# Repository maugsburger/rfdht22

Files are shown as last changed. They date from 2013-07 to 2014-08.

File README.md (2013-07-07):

rfdht22
=======

RF temp/hum sensor, grown from a DHT22 and NRF24L01p based sensor to something bigger.

Originally, I just wanted to monitor humidity and temperature in all rooms of my flat, submit them wireless to a master where you can read them out and get some other fancy features (eg close all windows, now it's warmer on the outside than inside).

sensor
------

With every step of hardware design, it grew a little bit bigger, so there are two different version right now:

- either a small headless version with dht22 or one-wire and i2c, powered by attiny2313a, as cheap as possible (single sided with some bridges)

- or a big version with lcd, twi/i2c, one-wire, quad direct analogue and quad opamp driven analogue in

One design goal was to make the sensors as power saving as possible, so they will hopefully run multiple years on a pair of AA cells. No wires, no problem with WAF.

master
------

Power doesn't matter here, big ass display (currently only 4x20 character LCD), can show values of all sensors, and a lot of planned features still in my head.

possible improvements
---------------------

 - lan interface for master
 - hack some radiator controller to enable remote control

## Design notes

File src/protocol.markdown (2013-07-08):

# RF Communication Protocol/Procedure

## Terms

* Sensor: autonomous device with probes attached to it, every sensor has its
  own 7-bit-id in range `0x01` to `0xFF`).
    * Probe: Every single measurement device attached to a sensor
* Master: device recieving all measurements for further processing, ID is
  always `0x00`
* PTX: The sender, initiating communication, here every sensors
* PRX: The reciever, can't initiate transfer on it's own, here the master

## Adresses and Data Pipes

The used [nRF24L01+][0] chip has the ability to divide the data stream into up
to six data pipes, identified by unique addresses.

Each address consists of up to 5 bytes, with the following requirements:

<table>
<tr><th></th><th>Byte4</th><th>Byte3</th><th>Byte2</th><th>Byte1</th><th>Byte0</th></tr>
<tr><th>Pipe0</th><td>0b4</td><td>0b3</td><td>0b2</td><td>0b1</td><td>addr0</td></tr>
<tr><th>Pipe1</th><td>b4</td><td>b3</td><td>b2</td><td>b1</td><td>addr1</td></tr>
<tr><th>Pipe2</th><td>b4</td><td>b3</td><td>b2</td><td>b1</td><td>addr2</td></tr>
<tr><th>Pipe3</th><td>b4</td><td>b3</td><td>b2</td><td>b1</td><td>addr3</td></tr>
<tr><th>Pipe4</th><td>b4</td><td>b3</td><td>b2</td><td>b1</td><td>addr4</td></tr>
<tr><th>Pipe5</th><td>b4</td><td>b3</td><td>b2</td><td>b1</td><td>addr5</td></tr>
</table>

As a special requirement, addr0-addr5 must be different.

Pipe0 will be used as a general transmit permission request line with
`addr0=0x00`, and every further pipe gets dynamically assigned to a sensors,
using the sensors ID as addrX.

Only 3 byte adresses will be used, so the sent packages can be shorter.
Therefore, byte2 and byte1 are the unique system id, byte3 and byte4 are unused

## Auto-Ack and Payload

In my reading of the datasheet, Auto-Ack always takes the payload in the TX
FIFO of PRX and sends it to the PTX. As there can be only 3 payloads pending,
there is no benifit in using more than 3 data pipes and therefore 2 sensor
connections at once.

Pipe0 has Auto-Ack disabled, so that the master has time to put the specific
reply packet in the TX buffer. 

A communication process will look like the following:

1. PTX sends out communication request packet on Pipe0
    * free pipe: 
        1. set up pipeX with sensors id as addrX
        1. put ack packet into tx fifo for pipeX
        1. send out ack with sensor id as payload
    * no free pipe:
        1. ack with payload 0x00
1. PTX sends out transfer config/informational packet on pipeX
    * master auto acks with informational data packet
1. PTX sends out one packet for every reading
    * master auto acks

## RF Packets, rev0

### Pipe0 request

    payload[0] = sensor_id
    payload[1], lower nibble = packet design revision = 0x0
    payload[1], higher nibble = desired action
        bit4    data
        bit5    config
        bit6    unused
        bit7    new_sensor (sensor_id must be 0 here!)
        exactly one bit must be set

### Pipe0 ACK

    payload[0] = sensor_id (set to assigned sensor_id in case of config)
    payload[1], lower nibble = packet design revision (if smaller than
        requested, this is max. revision of master and comm is terminated)
    payload[1], higher nibble = repeat and confirm desired action
        bit4    ack data
        bit5    ack config
        bit6    unused
        bit7    ack new_sensor (set sensor_id!)
        no bit set means no free transmit pipe, try again later

### Data
#### PipeX first packet

    payload[0] = battery reading
        0x00        => empty with comparator
        0xFF        => not empty with comparator
        0x01-0xFE   => voltage in .02 volt steps (up to 5.1V)
    payload[1], lower nibble = number of readings to transmit (up to 16)
    payload[1], higher nibble = needs update

#### PipeX first ACK

    payload[0] = transmit interval in 30s steps
    payload[1], lower nibble = outdoor brightness (adjust leds brightness)
    payload[1], higher nibble = unused

#### PipeX reading packets

    payload[0], xxDDPPPP
        xx      unused
        PPPP    probe id
        DD      bytes data to be recieved
    payload[1…4] = one to four probe data bytes

#### PipeX reading ACK

Auto-generated, empty
    
### Config

Althoug it would be nice to make the sensors configurable via master, this
feature is currently not available, because it would make the master need to
know about all sensors config details. This may be implemented in a future
protocol version.

There is no message back to the sensor if all masters probe channels are used,
too. In this case the sensors state is "all configured", but the master doesn't
know about the probes. 

#### PipeX config packet

As there can be up 32 bytes in a packet, but a sensor can only hold up to 16
probes, we just send a list of all sensors unit bytes.

    payload[n] = unit-data of sensor n

#### PipeX ACK

Auto-generated, empty

### New Sensor

No packets are needed, communication is over after Pipe0 ACK, but the
client should start a config dialogue directly afterwards.

## Thoughts
Up to 16 probes per sensor should be enough, else we need a sensor talking to
master as more than 1 sensor. 

Initially we need to brief the master about the known probes, especially their
data format and unit used. This should be splitted into two seperate processes,
a pairing of the sensor with the master (once) and probe configuration (every
time the probes change/new ones are added).

[0]: http://www.nordicsemi.com/kor/nordic/download_resource/8765/2/8827113 "nRF24L01+"

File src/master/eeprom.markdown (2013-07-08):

# EEPROM

Master has at least 2kB of EEPROM, splittet in blocks of 256 bytes here.

With this layout, there are 511 bytes for general usage available, the sensor
and probe data takes 1537 bytes.

Up to 255 sensors can be connected, combined with up to 1024 probes. Every char
in sensor description decrements the available sensor count by one.

## First kB
    0x000…0x01f automatically assigned
        free_sensor_id  first currently unused sensor id
    0x200…0x2ff sensor and probe data start – high section
        0x200: first free probe unit data byte (0x4LL…0x7LL) and length of
                sensor0 description text
        0x201…0x2ff: sensor1-255 probe data start byte (0x4LL…0x7LL) and length of
                sensor1-255 description text
        TTTTTTHH
        TTTTTT  0-64 chars of descriptive text
        HH      0-3 high sector, 0x4LL - 0x7LL
    0x300…0x3ff sensor and probe data start – low section
        0x300: first free probe unit data byte (0xH00…0xHff)
        0x301…0x3ff: sensor1-255 probe data start byte (0xH00…0xHff)

## Second kB
    1024 bytes of "shared" unit data/description string memory
    0x400…0x4ff probe0-255 unit data, according to units.md
    0x500…0x5ff 
    0x600…0x6ff
    0x700…0x7ff

# Examples
## Sensor/Probe Data

Setup with two sensors, first named 'TEST' has 2 probes temp and hum, second
named 'Foo23' has only one temp sensor
   
    free_sensor_id = 2

    0x200   00010000
            TTTTTTHH
            => TTTTTT = 100 => 4 bytes/chars of descriptive text for sensor0
            => HH = 00      => first free high byte is 0x4LL
    0x300   00001100        => first free low byte is  0xH0c

    0x201   00010100
            TTTTTTHH
            => TTTTTT = 101 => 5 bytes/chars of descriptive text for sensor1
            => HH = 00      => data start high byte is 0x4LL
    0x301   00000110        => data start low byte is  0xH06

    0x202…0x2ff --unused--
    0x302…0x3ff --unused--

    0x400   0x54    => 'T'
    0x401   0x60    => 'E'
    0x402   0x53    => 'S'
    0x403   0x54    => 'T'
    0x404   0x40    => °C, divide by 10
    0x405   0x41    => % hum, divide by 10
    0x406   0x46    => 'F'
    0x407   0x6F    => 'o'
    0x408   0x6F    => 'o'
    0x409   0x32    => '2'
    0x40a   0x33    => '3'
    0x40b   0x40    => °C, divide by 10
    0x40c…0x7ff --unused--

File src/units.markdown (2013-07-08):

# Available units

    one byte data, PPUU UUUU

6 bits available for unit

    0x00    °C
    0x01    % hum
    …
    0x3F

2 bits available for prescaling

   00   do nothing
   01   divide by 10
   10   divide by 100
   11   divide by 1000

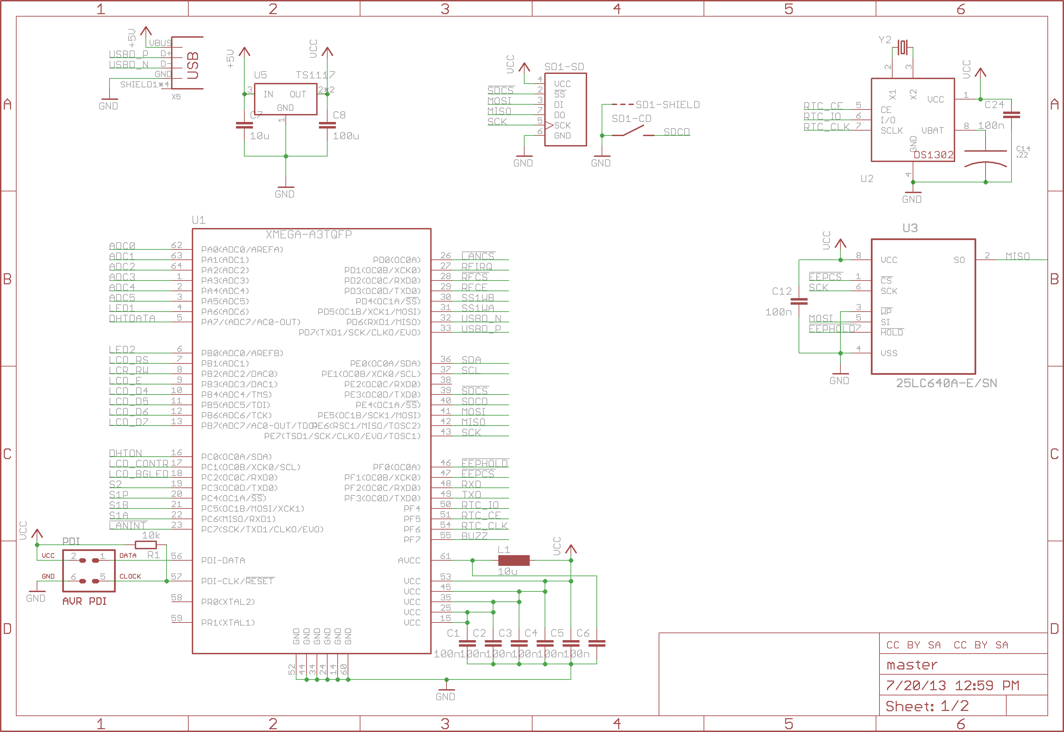
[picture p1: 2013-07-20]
master_sheet1.png

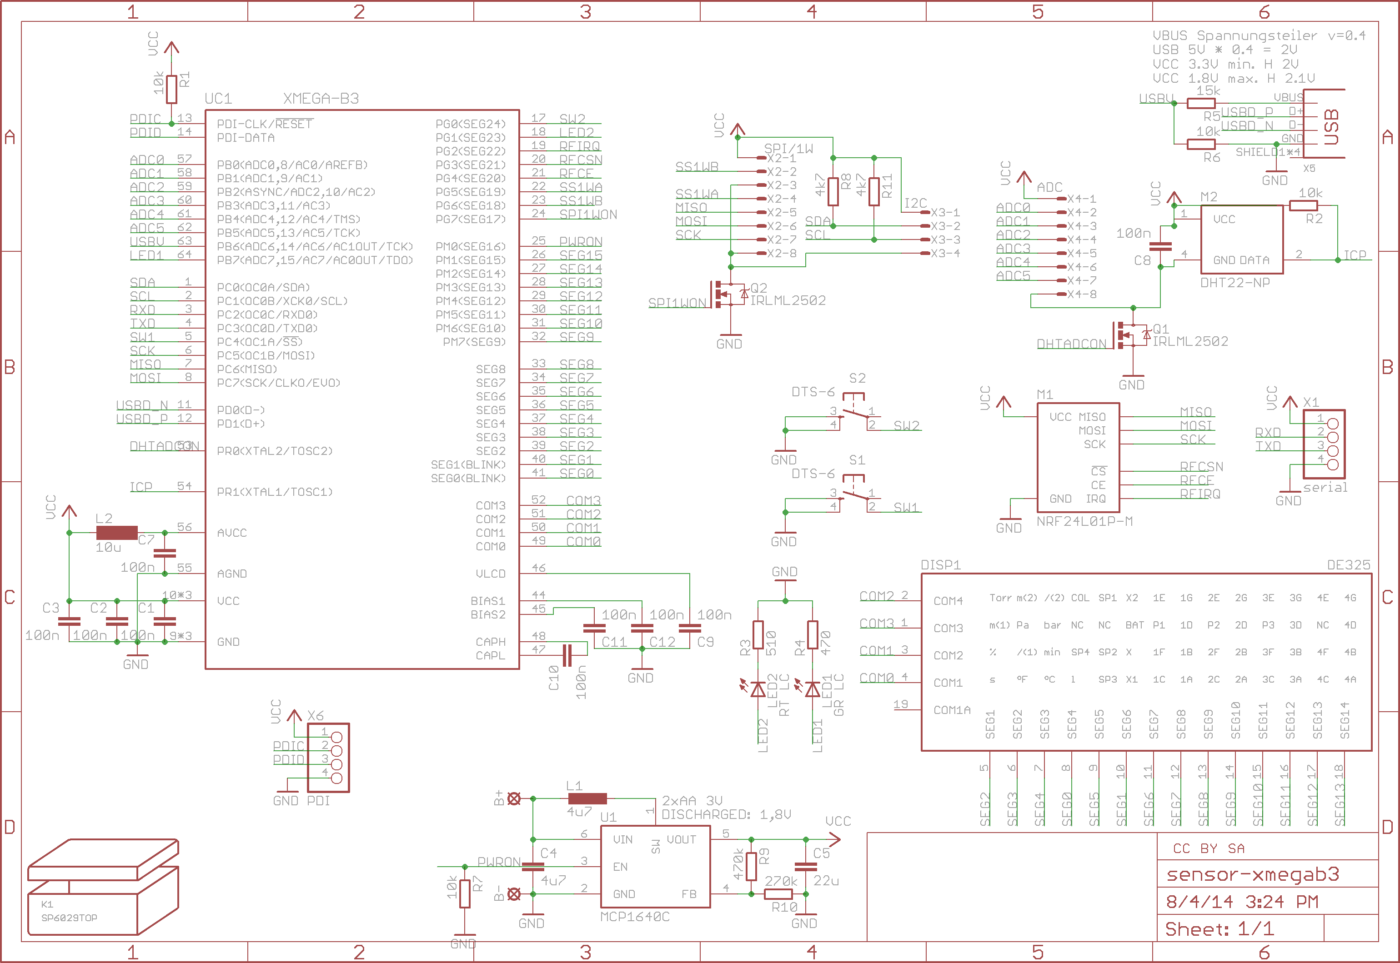
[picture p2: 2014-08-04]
sensor-xmegab3_sheet1.png

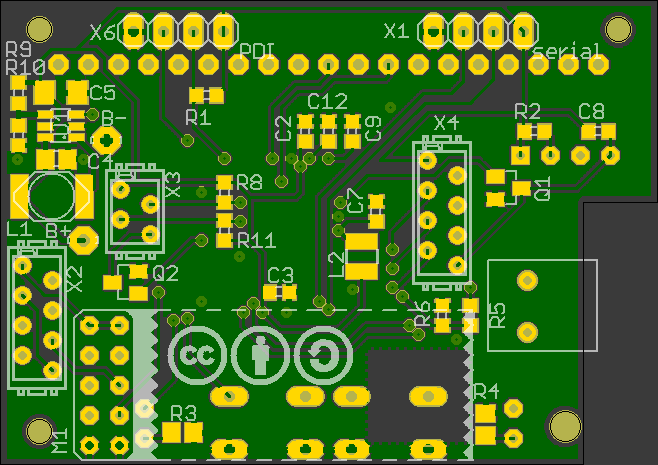
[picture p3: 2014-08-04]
sensor-xmegab3_bot.png

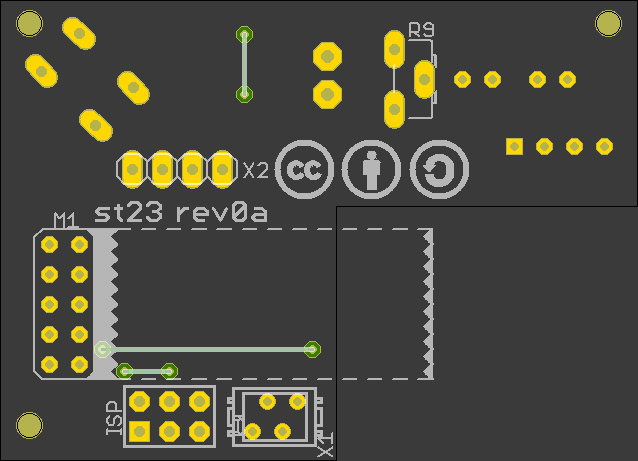
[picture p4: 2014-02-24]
sensor-tiny2313a_bot.png

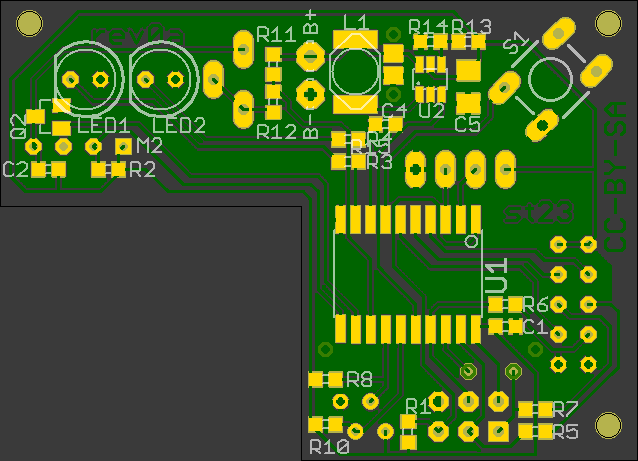
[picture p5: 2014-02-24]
sensor-tiny2313a_top.png

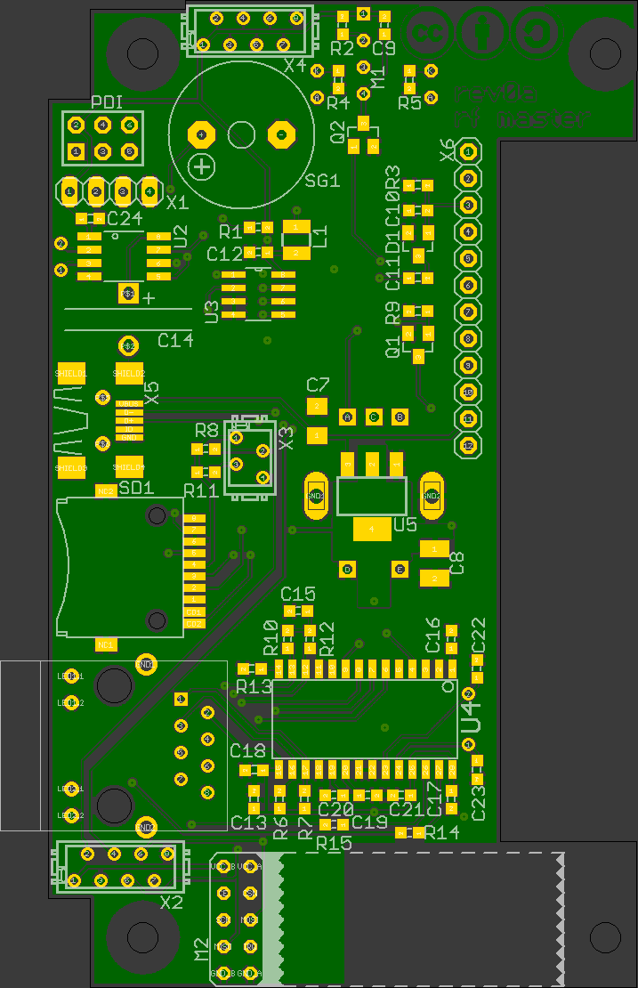
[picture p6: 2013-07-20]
master_bot.png

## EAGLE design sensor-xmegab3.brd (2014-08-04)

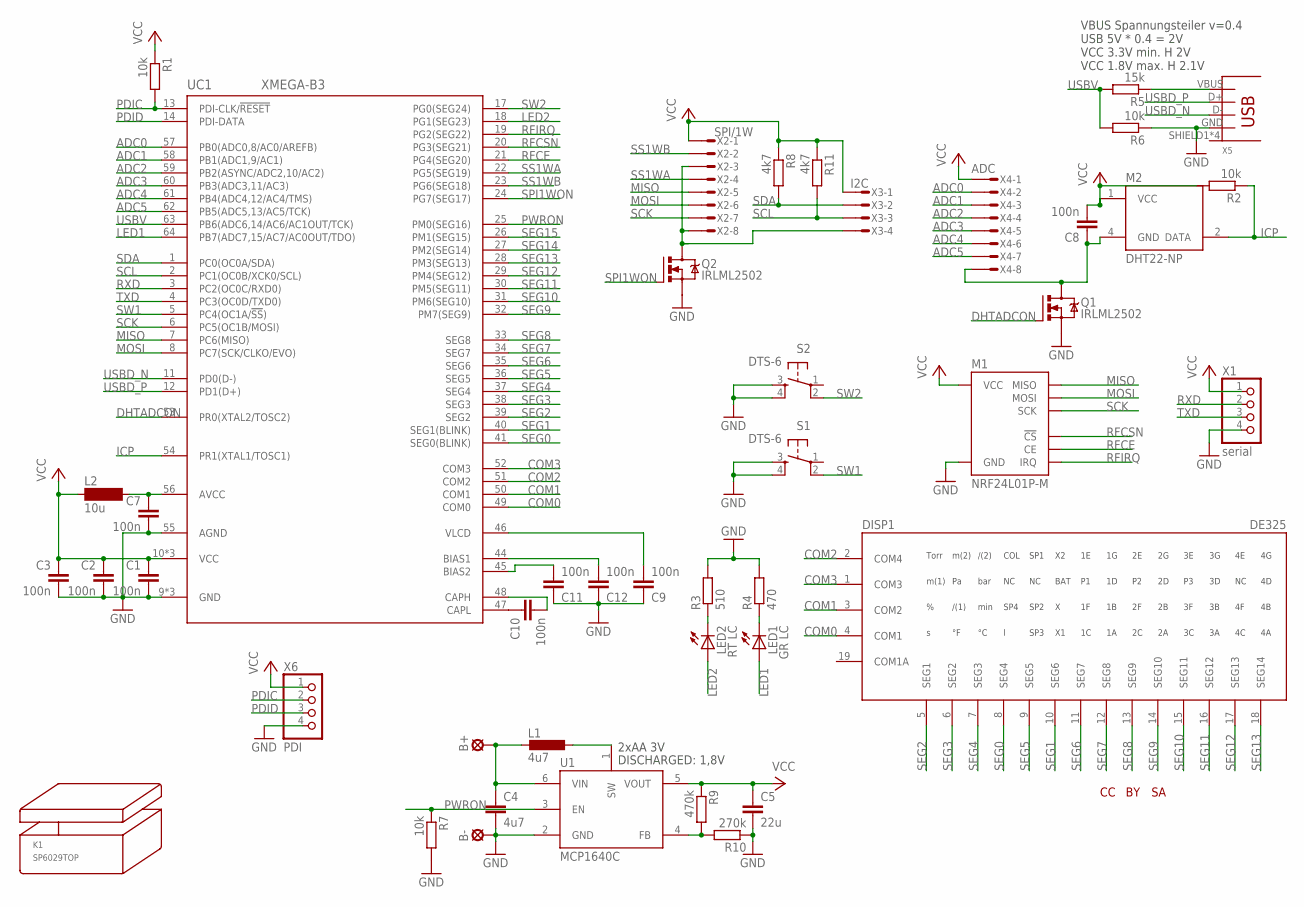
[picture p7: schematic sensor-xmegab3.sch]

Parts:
B+: LSP11
B-: LSP11
C1, C2, C3, C7, C8, C9, C10, C11, C12: 100n; C0603
C4: 4u7; C0805
C5: 22u; C1206
DISP1: DE325
K1: SP6029TOP; SP6029T
L1: 4u7; PISG
L2: 10u; SM-NE29
LED1: GR LC; LED5MM
LED2: RT LC; LED5MM
M1: NRF24L01P-M; NRF24L01P-A
M2: DHT22-NP; DHT22-NOPRINT
Q1, Q2: IRLML2502; MICRO3
R1, R2, R6, R7: 10k; R0603
R3: 510; R0805
R4: 470; R0805
R5: 15k; R0603
R8, R11: 4k7; R0603
R9: 470k; R0603
R10: 270k; R0603
S1, S2: DTS-6
U1: MCP1640C; SOT23-6
U$1: CC-TPLACE-HALF; CC_TPLACE_HS
U$3: BY-TPLACE-HS; BY_TPLACE_HS
U$4: SA-TPLACE-HALF; SA_TPLACE_HS
UC1: XMEGA-B3; TQFP64
X1: serial; 1X04
X2: SPI/1W; MICROMATCH-8
X3: I2C; MICROMATCH-4
X4: ADC; MICROMATCH-8
X5: USB; USB-MB-S
X6: PDI; 1X04

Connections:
ADC0: UC1.57 (PB0(ADC0,8/AC0/AREFB)), X4.2
ADC1: UC1.58 (PB1(ADC1,9/AC1)), X4.3
ADC2: UC1.59 (PB2(ASYNC/ADC2,10/AC2)), X4.4
ADC3: UC1.60 (PB3(ADC3,11/AC3)), X4.5
ADC4: UC1.61 (PB4(ADC4,12/AC4/TMS)), X4.6
ADC5: UC1.62 (PB5(ADC5,13/AC5/TCK)), X4.7
AVCC: C7.1, L2.2, UC1.56 (AVCC)
COM0: DISP1.4 (COM1), UC1.49 (COM0)
COM1: DISP1.3 (COM2), UC1.50 (COM1)
COM2: DISP1.2 (COM4), UC1.51 (COM2)
COM3: DISP1.1 (COM3), UC1.52 (COM3)
DHTADCON: Q1.1 (G), UC1.53 (PR0(XTAL2/TOSC2))
GND: B-.MP, C1.2, C2.2, C3.2, C4.2, C5.2, C7.2, C9.1, C11.1, C12.1, M1.GND_A (GND), M1.GND_B (GND), Q1.2 (S), Q2.2 (S), R3.2, R4.2, R6.1, R7.2, R10.1, S1.3, S1.4, S2.3, S2.4, U1.2 (GND), UC1.9 (GND), UC1.15 (GND), UC1.42 (GND), UC1.55 (AGND), X1.4, X5.GND, X6.4
ICP: M2.2 (DATA), R2.1, UC1.54 (PR1(XTAL1/TOSC1))
LED1: LED1.A, UC1.64 (PB7(ADC7,15/AC7/AC0OUT/TDO))
LED2: LED2.A, UC1.18 (PG1(SEG23))
MISO: M1.MISO, UC1.7 (PC6(MISO)), X2.5
MOSI: M1.MOSI, UC1.8 (PC7(SCK/CLKO/EVO)), X2.6
unnamed: LED1.K (C), R4.1
unnamed: R5.1, X5.VBUS
unnamed: LED2.K (C), R3.1
unnamed: L1.1, U1.1 (SW)
unnamed: R9.2, R10.2, U1.4 (FB)
unnamed: C11.2, UC1.45 (BIAS2)
unnamed: C12.2, UC1.44 (BIAS1)
unnamed: Q2.3 (D), X2.3, X2.8, X3.4
unnamed: C8.1, M2.4 (GND), Q1.3 (D), X4.8
unnamed: C9.2, UC1.46 (VLCD)
unnamed: C10.1, UC1.47 (CAPL)
unnamed: C10.2, UC1.48 (CAPH)
PDIC: R1.2, UC1.13 (PDI-CLK/!RESET), X6.2
PDID: UC1.14 (PDI-DATA), X6.3
PWRON: R7.1, U1.3 (EN), UC1.25 (PM0(SEG16))
RFCE: M1.CE, UC1.21 (PG4(SEG20))
RFCSN: M1.CSN (!CS), UC1.20 (PG3(SEG21))
RFIRQ: M1.IRQ, UC1.19 (PG2(SEG22))
RXD: UC1.3 (PC2(OC0C/RXD0)), X1.2
SCK: M1.SCK, UC1.6 (PC5(OC1B/MOSI)), X2.7
SCL: R11.2, UC1.2 (PC1(OC0B/XCK0/SCL)), X3.3
SDA: R8.2, UC1.1 (PC0(OC0A/SDA)), X3.2
SEG0: DISP1.8 (SEG4), UC1.41 (SEG0(BLINK))
SEG1: DISP1.10 (SEG6), UC1.40 (SEG1(BLINK))
SEG2: DISP1.5 (SEG1), UC1.39 (SEG2)
SEG3: DISP1.6 (SEG2), UC1.38 (SEG3)
SEG4: DISP1.7 (SEG3), UC1.37 (SEG4)
SEG5: DISP1.9 (SEG5), UC1.36 (SEG5)
SEG6: DISP1.11 (SEG7), UC1.35 (SEG6)
SEG7: DISP1.12 (SEG8), UC1.34 (SEG7)
SEG8: DISP1.13 (SEG9), UC1.33 (SEG8)
SEG9: DISP1.14 (SEG10), UC1.32 (PM7(SEG9))
SEG10: DISP1.15 (SEG11), UC1.31 (PM6(SEG10))
SEG11: DISP1.16 (SEG12), UC1.30 (PM5(SEG11))
SEG12: DISP1.17 (SEG13), UC1.29 (PM4(SEG12))
SEG13: DISP1.18 (SEG14), UC1.28 (PM3(SEG13))
SEG14: UC1.27 (PM2(SEG14))
SEG15: UC1.26 (PM1(SEG15))
SPI1WON: Q2.1 (G), UC1.24 (PG7(SEG17))
SS1WA: UC1.22 (PG5(SEG19)), X2.4
SS1WB: UC1.23 (PG6(SEG18)), X2.2
SW1: S1.2, UC1.5 (PC4(OC1A/!SS!))
SW2: S2.2, UC1.17 (PG0(SEG24))
TXD: UC1.4 (PC3(OC0D/TXD0)), X1.3
USBD_N: UC1.11 (PD0(D-)), X5.D-
USBD_P: UC1.12 (PD1(D+)), X5.D+
USBV: R5.2, R6.2, UC1.63 (PB6(ADC6,14/AC6/AC1OUT/TCK))
VBAT: B+.MP, C4.1, L1.2, U1.6 (VIN)
VCC: C1.1, C2.1, C3.1, C5.1, C8.2, L2.1, M1.VCC_A (VCC), M1.VCC_B (VCC), M2.1 (VCC), R1.1, R2.2, R8.1, R9.1, R11.1, U1.5 (VOUT), UC1.10 (VCC), UC1.16 (VCC), UC1.43 (VCC), X1.1, X2.1, X3.1, X4.1, X6.1

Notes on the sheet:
2xAA 3V
DISCHARGED: 1,8V
VBUS Spannungsteiler v=0.4 USB 5V * 0.4 = 2V VCC 3.3V min. H 2V VCC 1.8V max. H 2.1V

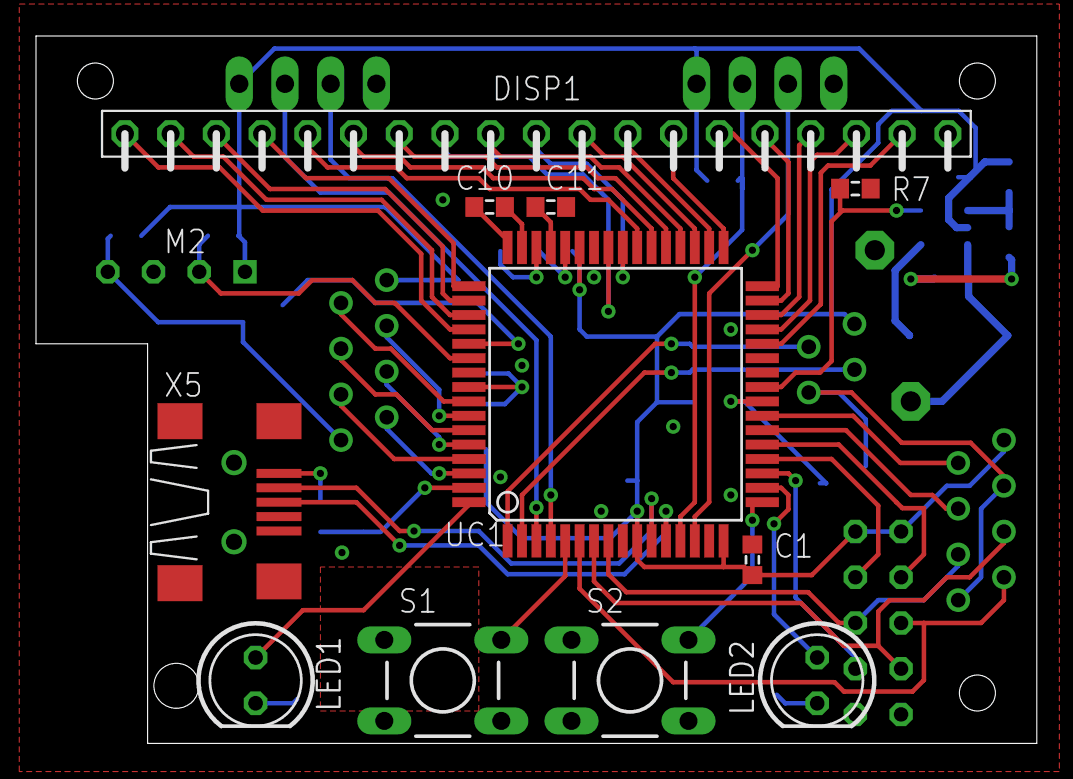
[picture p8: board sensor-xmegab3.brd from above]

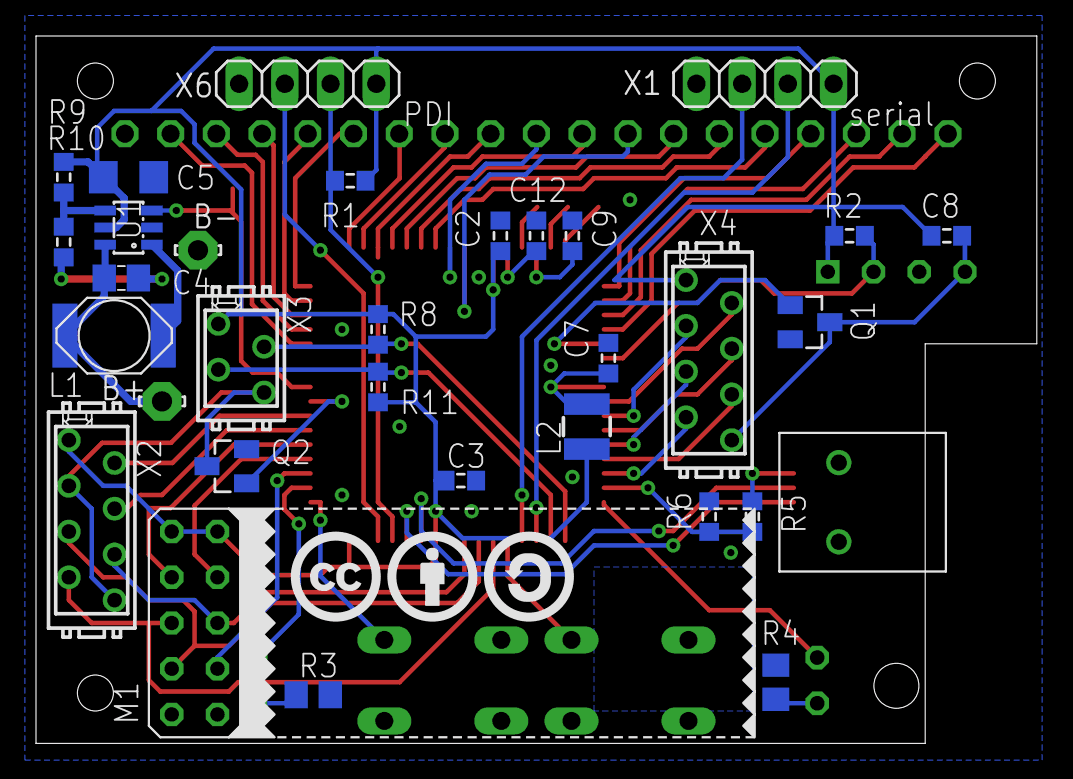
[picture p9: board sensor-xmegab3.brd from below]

Board: 2 copper layers, 55.6 x 39.3 mm, 47 parts (34 on the bottom side), 65 nets.

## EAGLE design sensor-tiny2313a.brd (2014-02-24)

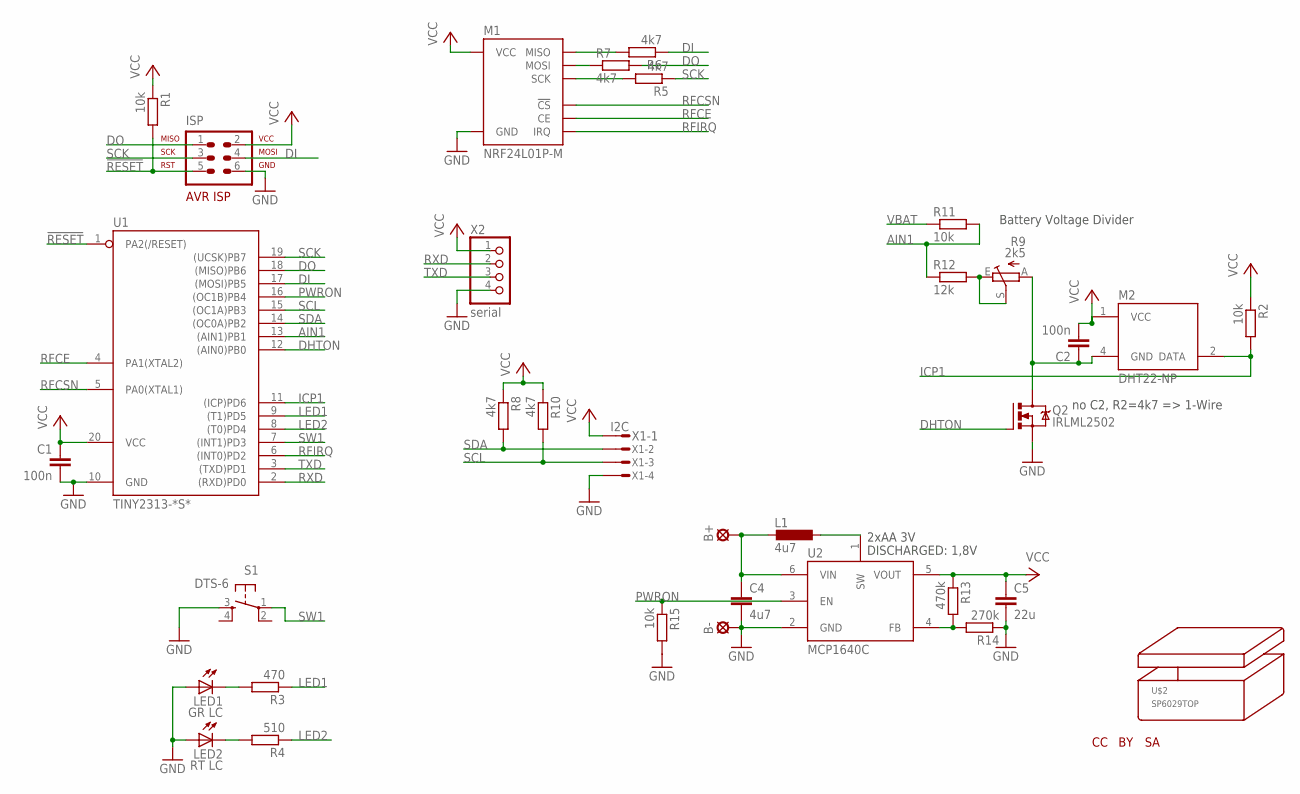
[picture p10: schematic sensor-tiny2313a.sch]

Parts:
B+: LSP11
B-: LSP11
C1, C2: 100n; C0603
C4: 4u7; C0805
C5: 22u; C1206
ISP: ML6; AVR-ISP-6
L1: 4u7; PISG
LED1: GR LC; LED5MM
LED2: RT LC; LED5MM
M1: NRF24L01P-M; NRF24L01P-A
M2: DHT22-NP; DHT22-NOPRINT
Q2: IRLML2502; MICRO3
R1, R2, R11, R15: 10k; R0603
R3: 470; R0603
R4: 510; R0603
R5, R6, R7, R8, R10: 4k7; R0603
R9: 2k5; CA6H
R12: 12k; R0603
R13: 470k; R0603
R14: 270k; R0603
S1: DTS-6
U1: TINY2313-*S*; SO20L$
U2: MCP1640C; SOT23-6
U$1: CC-TPLACE-HALF; CC_TPLACE_HS
U$2: SP6029TOP; SP6029T
U$3: BY-TPLACE-HS; BY_TPLACE_HS
U$4: SA-TPLACE-HALF; SA_TPLACE_HS
X1: I2C; MICROMATCH-4
X2: serial; 1X04

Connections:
!RESET: ISP.5, R1.2, U1.1 (PA2(/RESET))
AIN1: R11.2, R12.1, U1.13 ((AIN1)PB1)
DHTON: Q2.1 (G), U1.12 ((AIN0)PB0)
DI: ISP.4, R6.1, U1.17 ((MOSI)PB5)
DO: ISP.1, R7.2, U1.18 ((MISO)PB6)
GND: B-.MP, C1.2, C4.2, C5.2, ISP.6, LED1.A, LED2.A, M1.GND_A (GND), M1.GND_B (GND), Q2.2 (S), R14.1, R15.2, S1.3, U1.10 (GND), U2.2 (GND), X1.4, X2.4
ICP1: M2.2 (DATA), R2.2, U1.11 ((ICP)PD6)
LED1: R3.1, U1.9 ((T1)PD5)
LED2: R4.1, U1.8 ((T0)PD4)
unnamed: LED2.K (C), R4.2
unnamed: C2.1, M2.4 (GND), Q2.3 (D), R9.A
unnamed: LED1.K (C), R3.2
unnamed: R9.E, R9.S, R12.2
unnamed: L1.1, U2.1 (SW)
unnamed: R13.2, R14.2, U2.4 (FB)
PWRON: R15.1, U1.16 ((OC1B)PB4), U2.3 (EN)
RDI: M1.MISO, R6.2
RDO: M1.MOSI, R7.1
RFCE: M1.CE, U1.4 (PA1(XTAL2))
RFCSN: M1.CSN (!CS), U1.5 (PA0(XTAL1))
RFIRQ: M1.IRQ, U1.6 ((INT0)PD2)
RSCK: M1.SCK, R5.2
RXD: U1.2 ((RXD)PD0), X2.2
SCK: ISP.3, R5.1, U1.19 ((UCSK)PB7)
SCL: R10.2, U1.15 ((OC1A)PB3), X1.3
SDA: R8.2, U1.14 ((OC0A)PB2), X1.2
SW1: S1.1, U1.7 ((INT1)PD3)
TXD: U1.3 ((TXD)PD1), X2.3
VBAT: B+.MP, C4.1, L1.2, R11.1, U2.6 (VIN)
VCC: C1.1, C2.2, C5.1, ISP.2, M1.VCC_A (VCC), M1.VCC_B (VCC), M2.1 (VCC), R1.1, R2.1, R8.1, R10.1, R13.1, U1.20 (VCC), U2.5 (VOUT), X1.1, X2.1

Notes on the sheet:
Battery Voltage Divider
2xAA 3V
DISCHARGED: 1,8V
no C2, R2=4k7 => 1-Wire

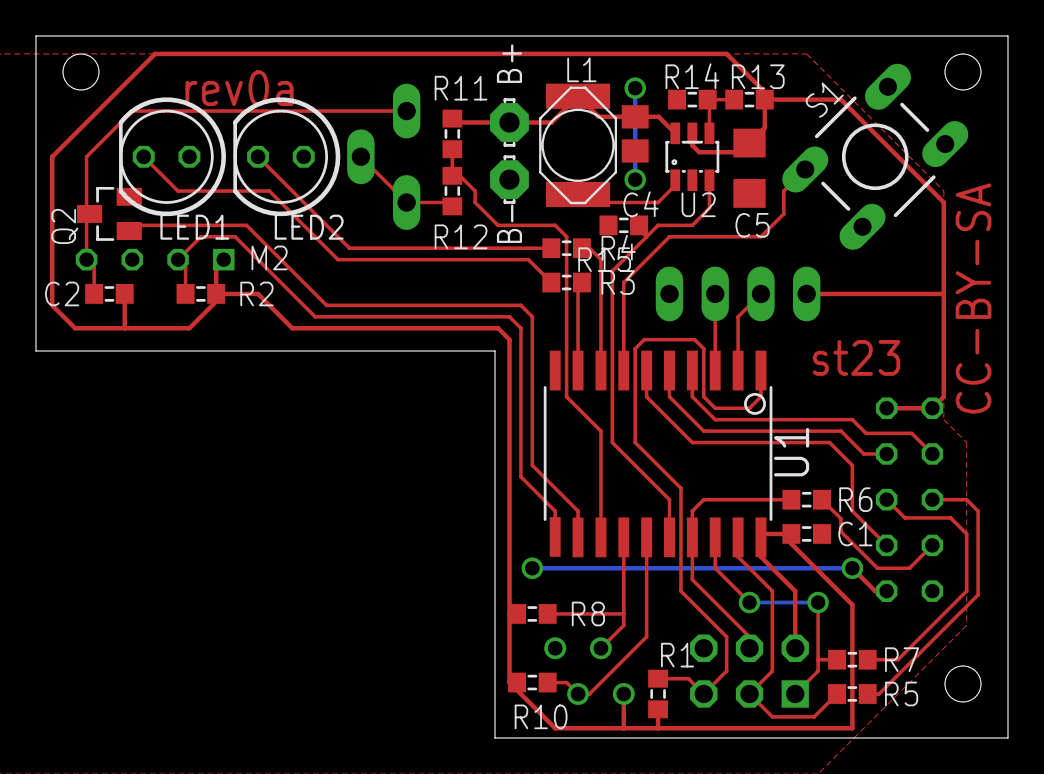
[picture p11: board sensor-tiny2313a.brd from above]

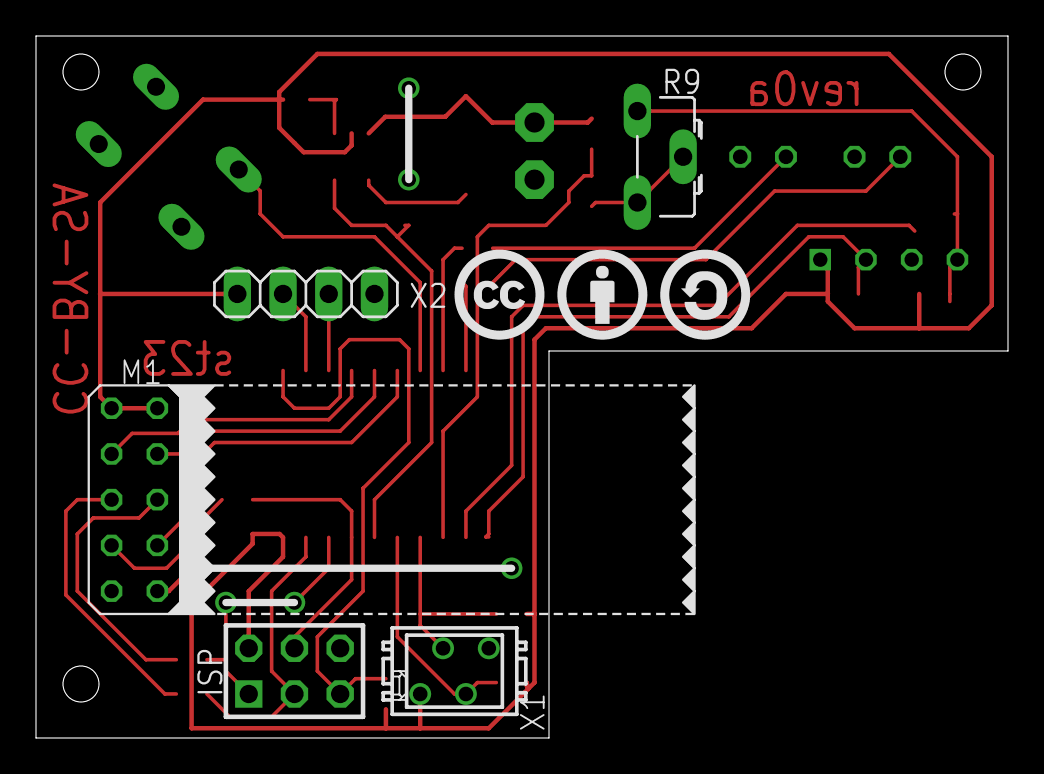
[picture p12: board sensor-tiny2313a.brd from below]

Board: 2 copper layers, 54.0 x 39.0 mm, 37 parts (8 on the bottom side), 30 nets.

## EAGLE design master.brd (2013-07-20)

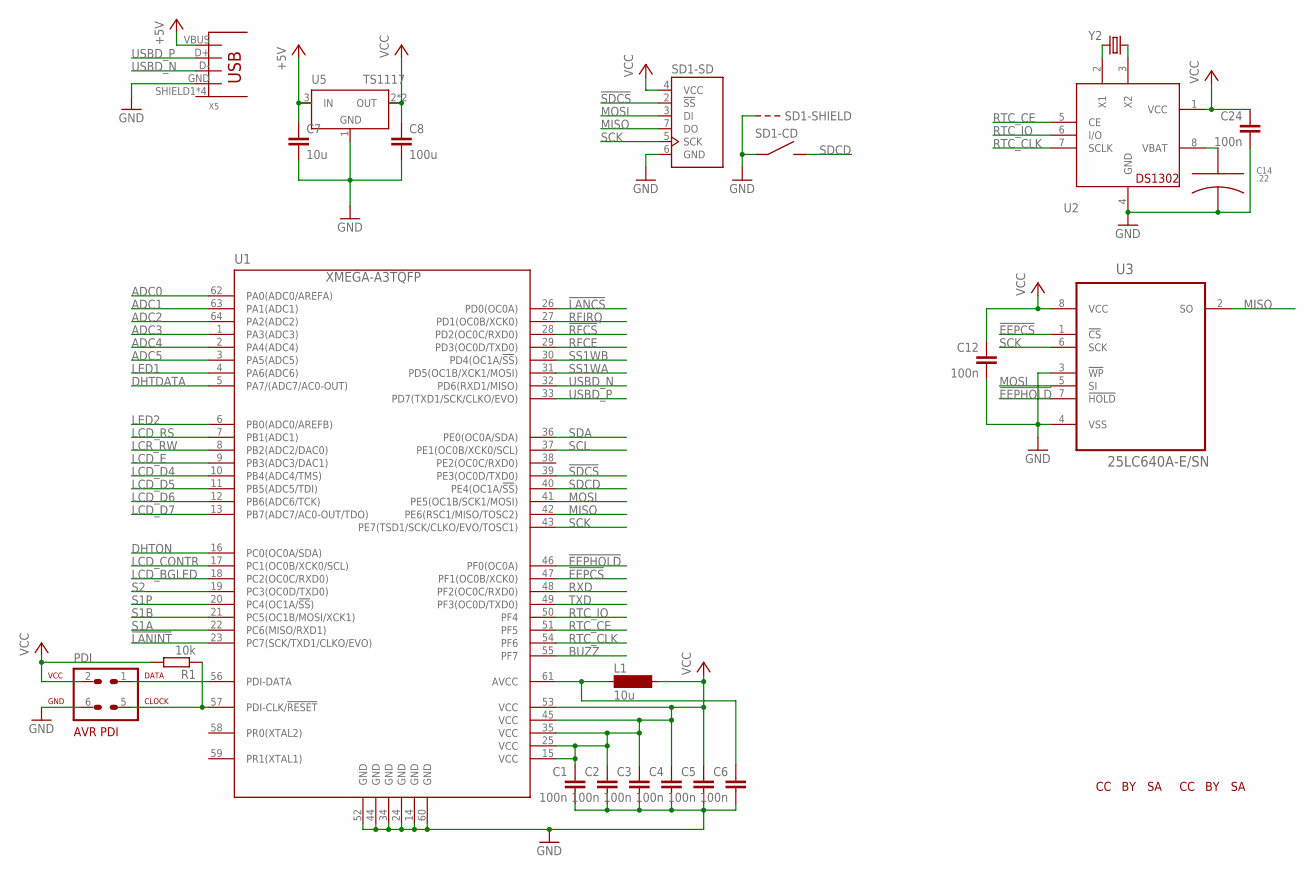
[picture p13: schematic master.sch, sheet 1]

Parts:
C1, C2, C3, C4, C5, C6, C12, C24: 100n; C0603
C7: 10u; C1206
C8: 100u; C1210
C14: .22; SUPERCAP
L1: 10u; SM-NE29
PDI: AVR-PDIVERT; AVR-ISP-6
R1: 10k; R0603
SD1: MICROSD_SW; MICROSD_SMD_EXTPIN
U1: XMEGA-A3TQFP; TQFP64
U2: DS1302SOIC; SOIC8_208MIL
U3: 25LC640A-E/SN; SOIC127P600X175-8N
U5: TS1117; SOT223
U$1: CC-TPLACE-HALF; CC_TPLACE_HS
U$2: BY-TPLACE-HS; BY_TPLACE_HS
U$7: SA-TPLACE-HALF; SA_TPLACE_HS
U$8: CC-TOP-HALF; CC_TOP_HS
U$9: BY-TOP-HALF; BY_TOP_HS
U$10: SA-TOP-HALF; SA_TOP_HS
X5: USB-MB-S
Y2: CRYSTALTC26H; TC26H

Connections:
!EEPCS: U1.47 (PF1(OC0B/XCK0)), U3.1 (!CS)
!EEPHOLD: U1.46 (PF0(OC0A)), U3.7 (!HOLD)
!LANCS: U1.26 (PD0(OC0A)); also elsewhere on the board
!LANINT: U1.23 (PC7(SCK/TXD1/CLKO/EVO)); also elsewhere on the board
!RFCS: U1.28 (PD2(OC0C/RXD0)); also elsewhere on the board
!SDCS: SD1.2 (!SS), U1.39 (PE3(OC0D/TXD0))
+5V: C7.1, U5.3 (IN), X5.VBUS; also elsewhere on the board
ADC0: U1.62 (PA0(ADC0/AREFA)); also elsewhere on the board
ADC1: U1.63 (PA1(ADC1)); also elsewhere on the board
ADC2: U1.64 (PA2(ADC2)); also elsewhere on the board
ADC3: U1.1 (PA3(ADC3)); also elsewhere on the board
ADC4: U1.2 (PA4(ADC4)); also elsewhere on the board
ADC5: U1.3 (PA5(ADC5)); also elsewhere on the board
BUZZ: U1.55 (PF7); also elsewhere on the board
DHTDATA: U1.5 (PA7/(ADC7/AC0-OUT)); also elsewhere on the board
DHTON: U1.16 (PC0(OC0A/SDA)); also elsewhere on the board
GND: C1.2, C2.2, C3.2, C4.2, C5.2, C6.2, C7.2, C8.2, C12.2, C14.P$2, C24.2, PDI.6, SD1.6 (GND), SD1.CD1, SD1.NC1 (SHIELD), SD1.NC2 (SHIELD), U1.14 (GND), U1.24 (GND), U1.34 (GND), U1.44 (GND), U1.52 (GND), U1.60 (GND), U2.4 (GND), U3.3 (!WP), U3.4 (VSS), U5.1 (GND), X5.GND; also elsewhere on the board
LCD_BGLED: U1.18 (PC2(OC0C/RXD0)); also elsewhere on the board
LCD_CONTR: U1.17 (PC1(OC0B/XCK0/SCL)); also elsewhere on the board
LCD_D4: U1.10 (PB4(ADC4/TMS)); also elsewhere on the board
LCD_D5: U1.11 (PB5(ADC5/TDI)); also elsewhere on the board
LCD_D6: U1.12 (PB6(ADC6/TCK)); also elsewhere on the board
LCD_D7: U1.13 (PB7(ADC7/AC0-OUT/TDO)); also elsewhere on the board
LCD_E: U1.9 (PB3(ADC3/DAC1)); also elsewhere on the board
LCD_RS: U1.7 (PB1(ADC1)); also elsewhere on the board
LCR_RW: U1.8 (PB2(ADC2/DAC0)); also elsewhere on the board
LED1: U1.4 (PA6(ADC6)); also elsewhere on the board
LED2: U1.6 (PB0(ADC0/AREFB)); also elsewhere on the board
MISO: SD1.7 (DO), U1.42 (PE6(RSC1/MISO/TOSC2)), U3.2 (SO); also elsewhere on the board
MOSI: SD1.3 (DI), U1.41 (PE5(OC1B/SCK1/MOSI)), U3.5 (SI); also elsewhere on the board
unnamed: U2.2 (X1), Y2.2
unnamed: U2.3 (X2), Y2.1
unnamed: C14.P$1, U2.8 (VBAT)
unnamed: PDI.1, U1.56 (PDI-DATA)
unnamed: PDI.5, R1.1, U1.57 (PDI-CLK/!RESET)
unnamed: C6.1, L1.1, U1.61 (AVCC)
RFCE: U1.29 (PD3(OC0D/TXD0)); also elsewhere on the board
RFIRQ: U1.27 (PD1(OC0B/XCK0)); also elsewhere on the board
RTC_CE: U1.51 (PF5), U2.5 (CE)
RTC_CLK: U1.54 (PF6), U2.7 (SCLK)
RTC_IO: U1.50 (PF4), U2.6 (I/O)
RXD: U1.48 (PF2(OC0C/RXD0)); also elsewhere on the board
S1A: U1.22 (PC6(MISO/RXD1)); also elsewhere on the board
S1B: U1.21 (PC5(OC1B/MOSI/XCK1)); also elsewhere on the board
S1P: U1.20 (PC4(OC1A/!SS!)); also elsewhere on the board
S2: U1.19 (PC3(OC0D/TXD0)); also elsewhere on the board
SCK: SD1.5 (SCK), U1.43 (PE7(TSD1/SCK/CLKO/EVO/TOSC1)), U3.6 (SCK); also elsewhere on the board
SCL: U1.37 (PE1(OC0B/XCK0/SCL)); also elsewhere on the board
SDA: U1.36 (PE0(OC0A/SDA)); also elsewhere on the board
SDCD: SD1.CD2, U1.40 (PE4(OC1A/!SS!))
SS1WA: U1.31 (PD5(OC1B/XCK1/MOSI)); also elsewhere on the board
SS1WB: U1.30 (PD4(OC1A/!SS!)); also elsewhere on the board
TXD: U1.49 (PF3(OC0D/TXD0)); also elsewhere on the board
USBD_N: U1.32 (PD6(RXD1/MISO)), X5.D-
USBD_P: U1.33 (PD7(TXD1/SCK/CLKO/EVO)), X5.D+
VCC: C1.1, C2.1, C3.1, C4.1, C5.1, C8.1, C12.1, C24.1, L1.2, PDI.2, R1.2, SD1.4 (VCC), U1.15 (VCC), U1.25 (VCC), U1.35 (VCC), U1.45 (VCC), U1.53 (VCC), U2.1 (VCC), U3.8 (VCC), U5.2 (OUT), U5.4 (OUT); also elsewhere on the board

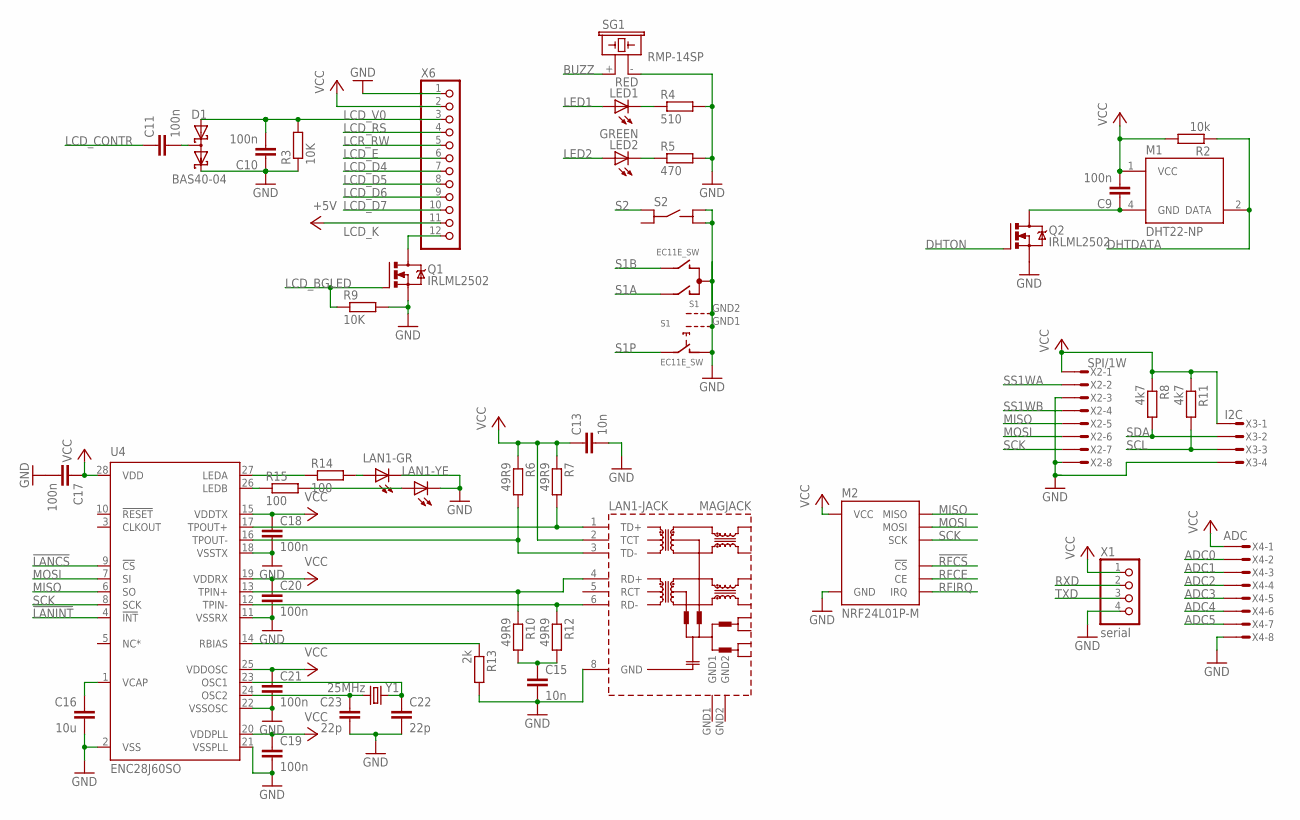
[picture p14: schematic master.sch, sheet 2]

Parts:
C9, C10, C11, C17, C18, C19, C20, C21: 100n; C0603
C13, C15: 10n; C0603
C16: 10u; C0603
C22, C23: 22p; C0603
D1: BAS40-04; SOT23
LAN1: MAGJACK
LED1: RED; LED5MM
LED2: GREEN; LED5MM
M1: DHT22-NP; DHT22-NOPRINT
M2: NRF24L01P-M; NRF24L01P-A
Q1, Q2: IRLML2502; MICRO3
R2: 10k; R0603
R3, R9: 10K; R0603
R4: 510; R0603
R5: 470; R0603
R6, R7, R10, R12: 49R9; R0603
R8, R11: 4k7; R0603
R13: 2k; R0603
R14, R15: 100; R0603
S1: EC11E_SW; ALPS_EC11E_SW
S2: MEC-SWITCHSMT; MEC-SMT
SG1: RMP-14SP; F/CM12P
U4: ENC28J60SO; SO28W
X1: serial; 1X04
X2: SPI/1W; MICROMATCH-8
X3: I2C; MICROMATCH-4
X4: ADC; MICROMATCH-8
X6: PINHD-1X12_2.54-R; 1X12R
Y1: 25MHz; HC49/S

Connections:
!LANCS: U4.9 (!CS); also elsewhere on the board
!LANINT: U4.4 (!INT); also elsewhere on the board
!RFCS: M2.CSN (!CS); also elsewhere on the board
+5V: X6.11; also elsewhere on the board
ADC0: X4.2; also elsewhere on the board
ADC1: X4.3; also elsewhere on the board
ADC2: X4.4; also elsewhere on the board
ADC3: X4.5; also elsewhere on the board
ADC4: X4.6; also elsewhere on the board
ADC5: X4.7; also elsewhere on the board
BUZZ: SG1.+ (1); also elsewhere on the board
DHTDATA: M1.2 (DATA), R2.1; also elsewhere on the board
DHTON: Q2.1 (G); also elsewhere on the board
GND: C10.1, C13.2, C15.2, C16.2, C17.2, C18.2, C19.2, C20.2, C21.2, C22.2, C23.2, D1.2 (C2), LAN1.8 (GND), LAN1.LED1.2 (C), LAN1.LED2.2 (C), M2.GND_A (GND), M2.GND_B (GND), Q1.2 (S), Q2.2 (S), R3.1, R4.2, R5.2, R9.2, R13.2, S1.C, S1.D (1), S1.GND1 (G), S1.GND2 (G), S2.3 (B1), S2.4 (B2), SG1.- (2), U4.2 (VSS), U4.11 (VSSRX), U4.18 (VSSTX), U4.21 (VSSPLL), U4.22 (VSSOSC), X1.4, X2.3, X2.8, X3.4, X4.8, X6.1; also elsewhere on the board
LCD_BGLED: Q1.1 (G), R9.1; also elsewhere on the board
LCD_CONTR: C11.1; also elsewhere on the board
LCD_D4: X6.7; also elsewhere on the board
LCD_D5: X6.8; also elsewhere on the board
LCD_D6: X6.9; also elsewhere on the board
LCD_D7: X6.10; also elsewhere on the board
LCD_E: X6.6; also elsewhere on the board
LCD_K: Q1.3 (D), X6.12
LCD_RS: X6.4; also elsewhere on the board
LCD_V0: C10.2, D1.1 (A1), R3.2, X6.3
LCR_RW: X6.5; also elsewhere on the board
LED1: LED1.A; also elsewhere on the board
LED2: LED2.A; also elsewhere on the board
MISO: M2.MISO, U4.6 (SO), X2.5; also elsewhere on the board
MOSI: M2.MOSI, U4.7 (SI), X2.6; also elsewhere on the board
unnamed: LED1.K (C), R4.1
unnamed: C11.2, D1.3 (C1A2)
unnamed: LED2.K (C), R5.1
unnamed: LAN1.4 (RD+), R10.1, U4.13 (TPIN+)
unnamed: C9.1, M1.4 (GND), Q2.3 (D)
unnamed: LAN1.6 (RD-), R12.1, U4.12 (TPIN-)
unnamed: LAN1.3 (TD-), R6.2, U4.16 (TPOUT-)
unnamed: LAN1.1 (TD+), R7.2, U4.17 (TPOUT+)
unnamed: C15.1, R10.2, R12.2
unnamed: R13.1, U4.14 (RBIAS)
unnamed: C23.1, U4.24 (OSC2), Y1.1
unnamed: C22.1, U4.23 (OSC1), Y1.2
unnamed: C16.1, U4.1 (VCAP)
unnamed: R14.1, U4.27 (LEDA)
unnamed: R15.1, U4.26 (LEDB)
unnamed: LAN1.LED2.1 (A), R14.2
unnamed: LAN1.LED1.1 (A), R15.2
RFCE: M2.CE; also elsewhere on the board
RFIRQ: M2.IRQ; also elsewhere on the board
RXD: X1.2; also elsewhere on the board
S1A: S1.A; also elsewhere on the board
S1B: S1.B; also elsewhere on the board
S1P: S1.E (2); also elsewhere on the board
S2: S2.1 (A1); also elsewhere on the board
SCK: M2.SCK, U4.8 (SCK), X2.7; also elsewhere on the board
SCL: R11.2, X3.3; also elsewhere on the board
SDA: R8.2, X3.2; also elsewhere on the board
SS1WA: X2.2; also elsewhere on the board
SS1WB: X2.4; also elsewhere on the board
TXD: X1.3; also elsewhere on the board
VCC: C9.2, C13.1, C17.1, C18.1, C19.1, C20.1, C21.1, LAN1.2 (TCT), M1.1 (VCC), M2.VCC_A (VCC), M2.VCC_B (VCC), R2.2, R6.1, R7.1, R8.1, R11.1, U4.15 (VDDTX), U4.19 (VDDRX), U4.20 (VDDPLL), U4.25 (VDDOSC), U4.28 (VDD), X1.1, X2.1, X3.1, X4.1, X6.2; also elsewhere on the board

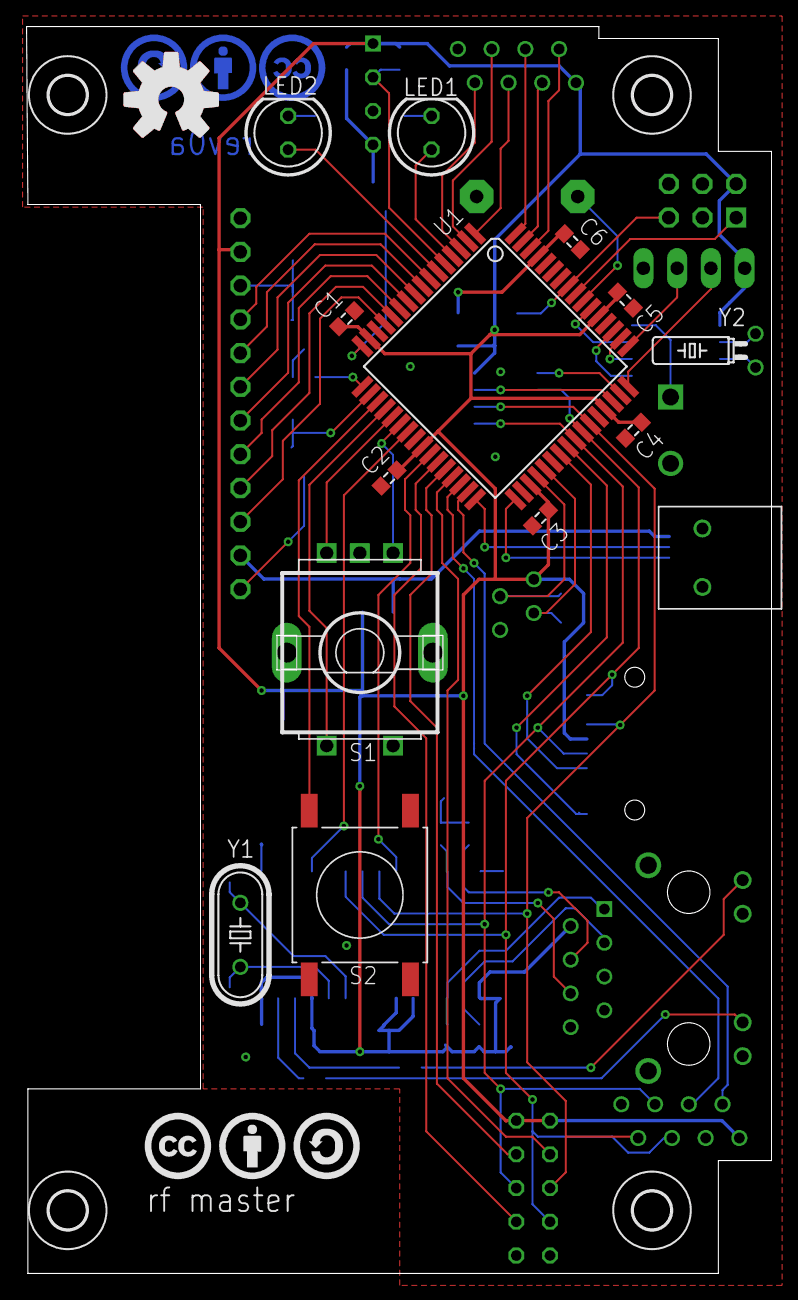
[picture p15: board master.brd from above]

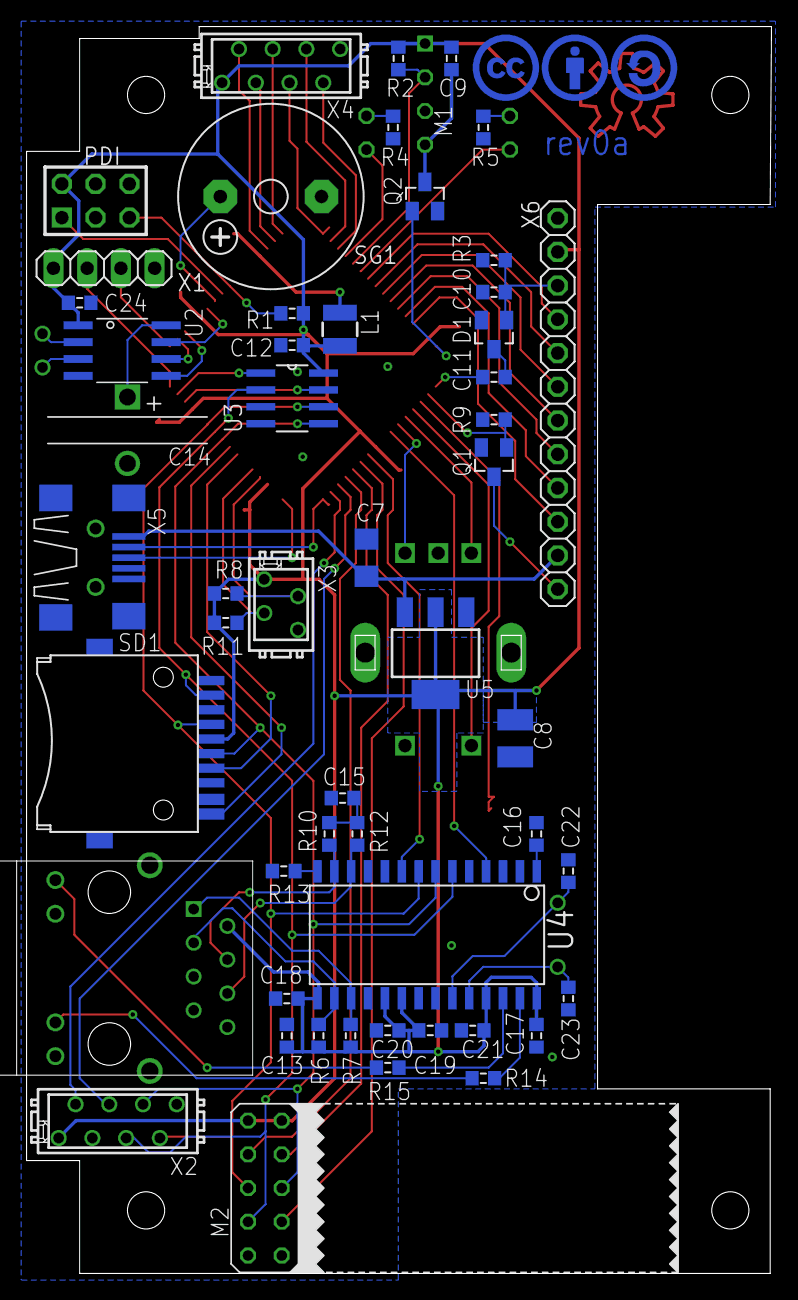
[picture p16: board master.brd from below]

Board: 2 copper layers, 56.1 x 93.9 mm, 76 parts (56 on the bottom side), 75 nets.

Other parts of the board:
U$3, U$4, U$5, U$6: 2,8

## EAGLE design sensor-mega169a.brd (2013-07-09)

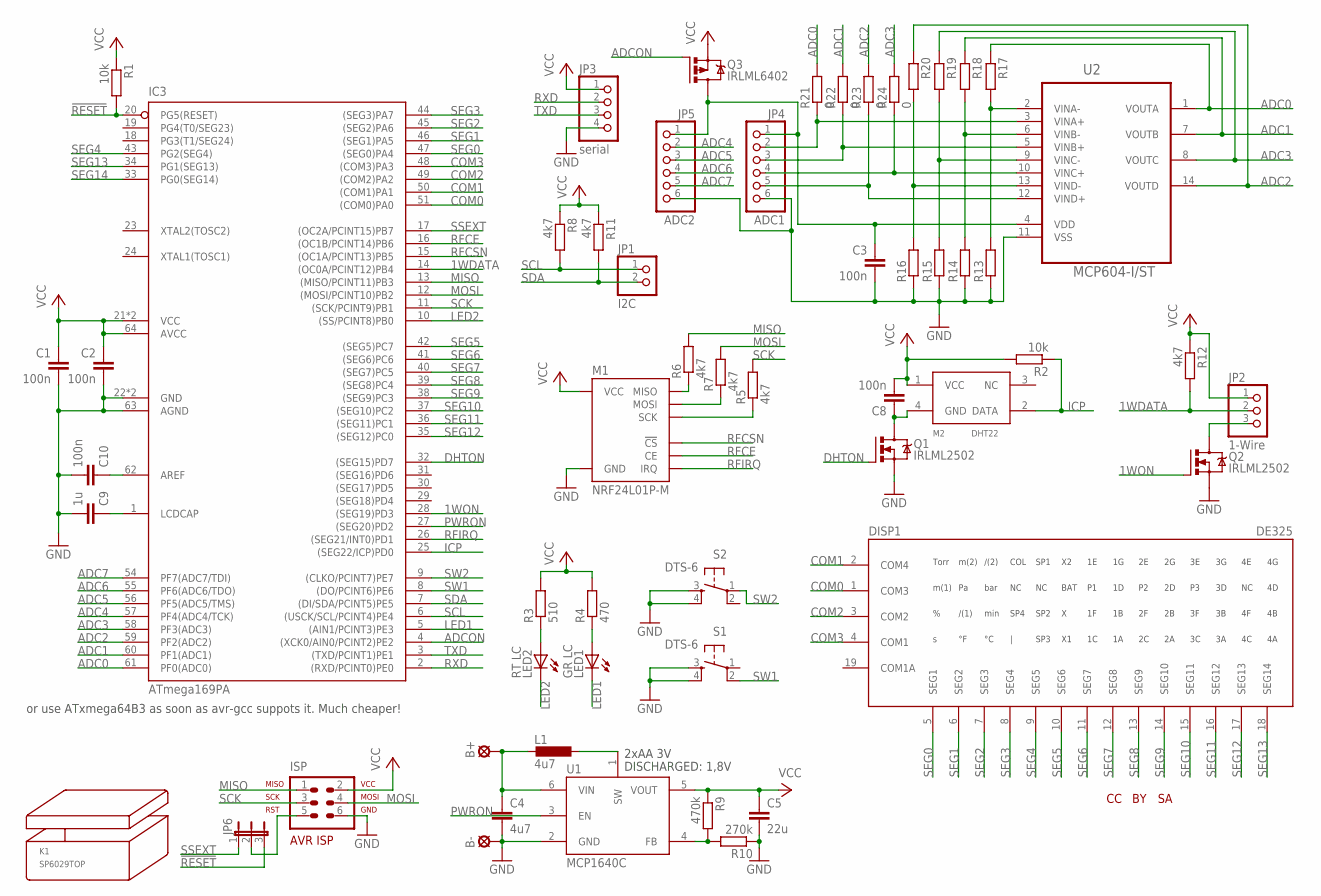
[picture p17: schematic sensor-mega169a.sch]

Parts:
B+: LSP11
B-: LSP11
C1, C2, C3, C8, C10: 100n; C0603
C4: 4u7; C0805
C5: 22u; C1206
C9: 1u; C0603
DISP1: DE325
IC3: ATmega169PA; TQFP64
ISP: ML6; AVR-ISP-6
JP1: I2C; 1X02
JP2: 1-Wire; 1X03
JP3: serial; 1X04
JP4: ADC1; 1X06
JP5: ADC2; 1X06
JP6: JP2E; JP2
K1: SP6029TOP; SP6029T
L1: 4u7; PISG
LED1: GR LC; LED5MM
LED2: RT LC; LED5MM
M1: NRF24L01P-M; NRF24L01P-A
M2: DHT22
Q1, Q2: IRLML2502; MICRO3
Q3: IRLML6402; MICRO3
R1, R2: 10k; R0603
R3: 510; R0805
R4: 470; R0805
R5, R6, R7, R8, R11, R12: 4k7; R0603
R9: 470k; R0603
R10: 270k; R0603
R13, R14, R15, R16, R17, R18, R19, R20: R-EU_R0603; R0603
R21, R22, R23, R24: 0; R0201
S1, S2: DTS-6
U1: MCP1640C; SOT23-6
U2: MCP604-I/ST; SOP65P640X120-14N
U$1: CC-TPLACE-HALF; CC_TPLACE_HS
U$3: BY-TPLACE-HS; BY_TPLACE_HS
U$4: SA-TPLACE-HALF; SA_TPLACE_HS

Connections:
1WDATA: IC3.14 ((OC0A/PCINT12)PB4), JP2.2, R12.2
1WON: IC3.28 ((SEG19)PD3), Q2.1 (G)
!RESET: IC3.20 (PG5(RESET)), JP6.3, R1.2
ADC0: IC3.61 (PF0(ADC0)), R17.1, R21.2, U2.1 (VOUTA)
ADC1: IC3.60 (PF1(ADC1)), R18.1, R22.2, U2.7 (VOUTB)
ADC2: IC3.59 (PF2(ADC2)), R20.1, R23.2, U2.14 (VOUTD)
ADC3: IC3.58 (PF3(ADC3)), R19.1, R24.2, U2.8 (VOUTC)
ADC4: IC3.57 (PF4(ADC4/TCK)), JP5.2
ADC5: IC3.56 (PF5(ADC5/TMS)), JP5.3
ADC6: IC3.55 (PF6(ADC6/TDO)), JP5.4
ADC7: IC3.54 (PF7(ADC7/TDI)), JP5.5
ADCON: IC3.4 ((XCK0/AIN0/PCINT2)PE2), Q3.1 (G)
AREF: C10.1, IC3.62 (AREF)
COM0: DISP1.1 (COM3), IC3.51 ((COM0)PA0)
COM1: DISP1.2 (COM4), IC3.50 ((COM1)PA1)
COM2: DISP1.3 (COM2), IC3.49 ((COM2)PA2)
COM3: DISP1.4 (COM1), IC3.48 ((COM3)PA3)
DHTON: IC3.32 ((SEG15)PD7), Q1.1 (G)
GND: B-.MP, C1.2, C2.2, C3.2, C4.2, C5.2, C9.2, C10.2, IC3.22 (GND), IC3.53 (GND), IC3.63 (AGND), ISP.6, JP3.4, JP4.6, JP5.6, M1.GND_A (GND), M1.GND_B (GND), Q1.2 (S), Q2.2 (S), R10.1, R13.1, R14.1, R15.1, R16.1, S1.3, S1.4, S2.3, S2.4, U1.2 (GND), U2.11 (VSS)
ICP: IC3.25 ((SEG22/ICP)PD0), M2.2 (DATA), R2.1
LCDCAP: C9.1, IC3.1 (LCDCAP)
LED1: IC3.5 ((AIN1/PCINT3)PE3), LED1.K (C)
LED2: IC3.10 ((SS/PCINT8)PB0), LED2.K (C)
MISO: IC3.13 ((MISO/PCINT11)PB3), ISP.1, R6.2
MOSI: IC3.12 ((MOSI/PCINT10)PB2), ISP.4, R7.2
unnamed: LED2.A, R3.1
unnamed: C8.1, M2.4 (GND), Q1.3 (D)
unnamed: M1.MISO, R6.1
unnamed: M1.MOSI, R7.1
unnamed: M1.SCK, R5.1
unnamed: ISP.5, JP6.2
unnamed: L1.1, U1.1 (SW)
unnamed: R9.2, R10.2, U1.4 (FB)
unnamed: JP2.3, Q2.3 (D)
unnamed: LED1.A, R4.1
unnamed: JP4.2, R21.1, U2.3 (VINA+)
unnamed: C3.1, JP4.1, JP5.1, Q3.3 (D), U2.4 (VDD)
unnamed: R16.2, R20.2, U2.13 (VIND-)
unnamed: R15.2, R19.2, U2.9 (VINC-)
unnamed: R14.2, R18.2, U2.6 (VINB-)
unnamed: R13.2, R17.2, U2.2 (VINA-)
unnamed: JP4.3, R22.1, U2.5 (VINB+)
unnamed: JP4.5, R23.1, U2.12 (VIND+)
unnamed: JP4.4, R24.1, U2.10 (VINC+)
PWRON: IC3.27 ((SEG20)PD2), U1.3 (EN)
RFCE: IC3.16 ((OC1B/PCINT14)PB6), M1.CE
RFCSN: IC3.15 ((OC1A/PCINT13)PB5), M1.CSN (!CS)
RFIRQ: IC3.26 ((SEG21/INT0)PD1), M1.IRQ
RXD: IC3.2 ((RXD/PCINT0)PE0), JP3.2
SCK: IC3.11 ((SCK/PCINT9)PB1), ISP.3, R5.2
SCL: IC3.6 ((USCK/SCL/PCINT4)PE4), JP1.1, R8.2
SDA: IC3.7 ((DI/SDA/PCINT5)PE5), JP1.2, R11.2
SEG0: DISP1.5 (SEG1), IC3.47 ((SEG0)PA4)
SEG1: DISP1.6 (SEG2), IC3.46 ((SEG1)PA5)
SEG2: DISP1.7 (SEG3), IC3.45 ((SEG2)PA6)
SEG3: DISP1.8 (SEG4), IC3.44 ((SEG3)PA7)
SEG4: DISP1.9 (SEG5), IC3.43 (PG2(SEG4))
SEG5: DISP1.10 (SEG6), IC3.42 ((SEG5)PC7)
SEG6: DISP1.11 (SEG7), IC3.41 ((SEG6)PC6)
SEG7: DISP1.12 (SEG8), IC3.40 ((SEG7)PC5)
SEG8: DISP1.13 (SEG9), IC3.39 ((SEG8)PC4)
SEG9: DISP1.14 (SEG10), IC3.38 ((SEG9)PC3)
SEG10: DISP1.15 (SEG11), IC3.37 ((SEG10)PC2)
SEG11: DISP1.16 (SEG12), IC3.36 ((SEG11)PC1)
SEG12: DISP1.17 (SEG13), IC3.35 ((SEG12)PC0)
SEG13: DISP1.18 (SEG14), IC3.34 (PG1(SEG13))
SEG14: IC3.33 (PG0(SEG14))
SSEXT: IC3.17 ((OC2A/PCINT15)PB7), JP6.1
SW1: IC3.8 ((DO/PCINT6)PE6), S1.2
SW2: IC3.9 ((CLKO/PCINT7)PE7), S2.1
TXD: IC3.3 ((TXD/PCINT1)PE1), JP3.3
VBAT: B+.MP, C4.1, L1.2, U1.6 (VIN)
VCC: C1.1, C2.1, C5.1, C8.2, IC3.21 (VCC), IC3.52 (VCC), IC3.64 (AVCC), ISP.2, JP2.1, JP3.1, M1.VCC_A (VCC), M1.VCC_B (VCC), M2.1 (VCC), Q3.2 (S), R1.1, R2.2, R3.2, R4.2, R8.1, R9.1, R11.1, R12.1, U1.5 (VOUT)

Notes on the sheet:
2xAA 3V
DISCHARGED: 1,8V
or use ATxmega64B3 as soon as avr-gcc suppots it. Much cheaper!

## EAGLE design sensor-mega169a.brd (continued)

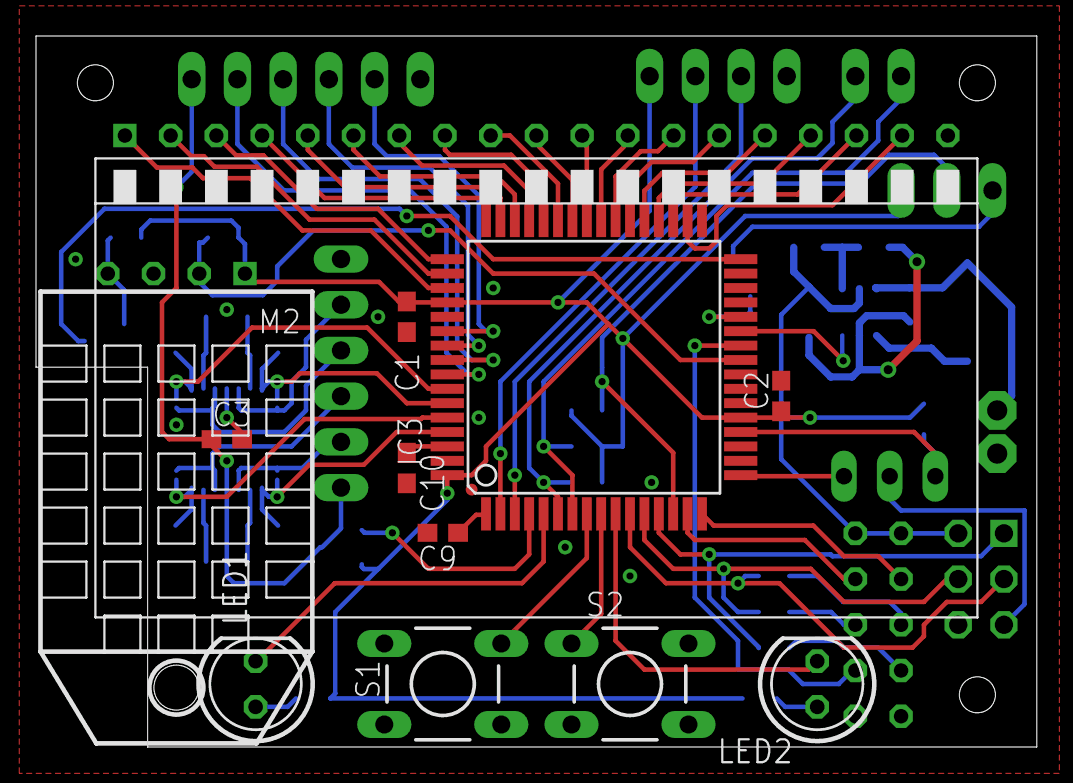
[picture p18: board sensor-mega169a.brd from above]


Board: 2 copper layers, 55.6 x 39.5 mm, 59 parts (46 on the bottom side), 72 nets.

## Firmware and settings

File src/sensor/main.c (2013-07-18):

/*
 * Copyright 2013 Moritz Augsburger <code@moritz.augsburger.name>
 *
 * This file is part of rfdht22.
 *
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
 */

#include "main.h"
volatile uint8_t isr_interval;

void dhtpwr_on() {
        // PB2 == OC0A
        TCCR0A =    (1<<WGM01) | (1<<WGM00) | //
                    (1<<COM0A1); // Clear OC0A on match, set at TOP
        TCCR0B = (0<<CS01) | (1<<CS00); // no prescaling
        OCR0A = 127;

        // PB2 und PB0 Ausgang
        DDRB |= (1<<PB2) | (1<<PB0);
        // PB0 VCC für Doubler
        PORTB |= (1<<PB0);
}

void dhtpwr_off() {
        // PB2 und PB1 kein Ausgang
        PORTB &= ~(1<<PB0);
        DDRB &= ~(1<<PB2) | (1<<PB0);
        TCCR0A = (0<<WGM01) | (0<<WGM00);
        TCCR0B = (0<<CS01) | (0<<CS00);     // stop counter
}

void sleep_time(uint8_t sleepmode, uint8_t intervals ) {
    wdt_reset();
    isr_interval = intervals;
    WDTCR = (1<<WDIF) | (1<<WDIE) | (1<<WDP3) | (1<<WDP0);
    while(isr_interval > 0) {
        set_sleep_mode(sleepmode);
        sleep_mode();
    }
    wdt_disable();
}

void blink(uint8_t c) {
    do {
        PORTA |= (1<<PA0);
        _delay_ms(100);
        PORTA &= ~(1<<PA0);
        _delay_ms(100);
        c--;
    } while (c>0);
    _delay_ms(500);
}

int main (void) {

    uint16_t temperature;
    uint16_t humidity;
    uint8_t  dht22res;

    uint8_t payload[wl_module_PAYLOAD];		//Array for Payload
	uint8_t k;
	
	wl_module_init();	    //initialise nRF24L01+ Module
	_delay_ms(50);		    //wait for nRF24L01+ Module
    wl_module_tx_config(wl_module_TX_NR_0);		//Config Module

 //   dhtpwr(true);

    PORTA = (1<<PA1) | (1<<PA0);
    DDRA  = (1<<PA0) | (1<<PA1);
    _delay_ms(500);

    while(1) {
        // measure
        PORTA = (1<<PA1);
        dht22res = dhtmeasure(&temperature, &humidity );
        PORTA = 0;

        for (k=0; k<=wl_module_PAYLOAD-1; k++) {
            payload[k] = k;
        }
        payload[0] = dht22res;
        payload[1] = temperature;
        payload[2] = (temperature>>8);
        payload[3] = humidity;
        payload[4] = (humidity>>8);

        sei();
        wl_module_send(payload,wl_module_PAYLOAD);
        _delay_ms(5000);

    }
}

ISR(WDT_OVERFLOW_vect) {
    isr_interval--; 
}

#if defined(__AVR_ATtiny2313__) || defined(__AVR_ATtiny2313A__)
ISR(INT0_vect) {
#endif
    uint8_t status;

    // Read wl_module status
    wl_module_CSN_lo;                               // Pull down chip select
    status = spi_fast_shift(NOP);					// Read status register
    wl_module_CSN_hi;                               // Pull up chip select

    // Package has been sent
    if (status & (1<<TX_DS)) {
        wl_module_config_register(STATUS, (1<<TX_DS));	//Clear Interrupt Bit
        PTX=0;
    }

    // IRQ: Package has not been sent, send again
    if (status & (1<<MAX_RT)) {
        wl_module_config_register(STATUS, (1<<MAX_RT));	// Clear Interrupt Bit
        wl_module_CE_hi;								// Start transmission
        _delay_us(10);								
        wl_module_CE_lo;
    }

    //TX_FIFO Full <-- this is not an IRQ
    if (status & (1<<TX_FULL)) {
        wl_module_CSN_lo;                               // Pull down chip select
        spi_fast_shift(FLUSH_TX);						// Flush TX-FIFO
        wl_module_CSN_hi;                               // Pull up chip select
    }
}
/*
static volatile uint8_t zahl[5];

        asm (   "sec"       "\n\t"
                "rol %0"    "\n\t"
                "rol %1"    "\n\t"
                "rol %2"    "\n\t"
                "rol %3"    "\n\t"
                "rol %4"
                :"+r"( zahl[4] ),
                 "+r"( zahl[3] ),
                 "+r"( zahl[2] ),
                 "+r"( zahl[1] ),
                 "+r"( zahl[0] ) );

=> 26 zyklen
*/

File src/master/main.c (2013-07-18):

/*
 * Copyright 2013 Moritz Augsburger <code@moritz.augsburger.name>
 *
 * This file is part of rfdht22.
 *
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
 */

#include <stdbool.h>
#include <stdlib.h>
#include <string.h>
#include <avr/io.h>
#include <util/delay.h>
#include <avr/interrupt.h> 
#define BAUD 9600
#include <util/setbaud.h>
#include <avr/pgmspace.h>
#include "lcd.h"
#include "wl_module.h"

#if F_CPU == 8000000 
    #define TCCR1DIVIDE (0<<CS12) | (1<<CS11) | (0<<CS10)
#elif F_CPU == 1000000 
    #define TCCR1DIVIDE (0<<CS12) | (0<<CS11) | (1<<CS10)
#else
    #error No supported CPU Freq
#endif

volatile uint8_t PTX;

int uart_putc(unsigned char c) {
    while (!(UCSR0A & (1<<UDRE0))){}  /* warten bis Senden moeglich */
    UDR0 = c;                      /* sende Zeichen */
    return 0;
}
 
/* puts ist unabhaengig vom Controllertyp */
void uart_puts (char *s) {
    while (*s) {   /* so lange *s != '\0' also ungleich dem "String-Endezeichen(Terminator)" */
        uart_putc(*s);
        s++;
    }
}

void dhtpwr( bool on ) {
    if( on ) {
        // PD6 == OC0A
        TCCR0A =    (1<<WGM01) | (1<<WGM00) | //
                    (1<<COM0A1); // Clear OC0A on match, set at TOP
        TCCR0B = (0<<CS01) | (1<<CS00); // no prescaling
        OCR0A = 127; 

        DDRD |= (1<<PD6);
    } else {
        // PB2 und PB1 kein Ausgang
        DDRD &= ~(1<<PD6);
        TCCR0A = (0<<WGM01) | (0<<WGM00);   //normal port operation
        TCCR0B = (0<<CS01) | (0<<CS00);     // stop counter
    }
}

void dhtpwrt(void) {
    if( DDRB & (1<<PB2) ) {
        dhtpwr(false);
    } else {
        dhtpwr(true);
    }
}

void lcd_itoa(uint8_t c) {
    char itoabuffer[9];
    itoa(c, itoabuffer, 2);
    for ( int i = strlen( itoabuffer ); i < 8; i++ ) {
        lcd_putc('0');
    } 
    lcd_puts(itoabuffer);
}

int main (void) {
    /* init serial */
    UCSR0B |= (1<<TXEN0);                // UART TX einschalten

    UCSR0C = (1 << UCSZ01)|(1 << UCSZ00); // Asynchron 8N1
    UBRR0H = UBRRH_VALUE;
    UBRR0L = UBRRL_VALUE;
    #if USE_2X
        UCSR0A |= (1 << U2X0);
    #else
        UCSR0A &= ~(1 << U2X0);
    #endif
    uart_puts("\n\rrestart\n\r");

    dhtpwr(1);
    lcd_init(LCD_DISP_ON);
    lcd_clrscr();
    lcd_puts("HELLO\n");

    char itoabuffer[20];
	uint8_t payload[wl_module_PAYLOAD];		//holds the payload
	uint8_t nRF_status;						//STATUS information of nRF24L01+
	uint8_t zaehler = 0;
	wl_module_init();		//Init nRF Module
	_delay_ms(50);			//wait for Module
//	sei();					//activate Interrupts
	wl_module_config();		//config nRF as RX Module, simple Version
    
    while(1) {
//        lcd_puts("waiting");
		while (!wl_module_data_ready());			//waits for RX_DR Flag in STATUS
		nRF_status = wl_module_get_data(payload);	//reads the incomming Data to Array payload
		lcd_clrscr();
		lcd_home();
        /*          1         2         3         4
         * 1........0.........0.........0.........0
         * 0 xxxxxxxx 1 xxxxxxxx 2 xxxxxxxx
         * 3 xxxxxxxx 4 xxxxxxxx 5 xxxxxxxx
         */
        lcd_gotoxy(10,0);
        lcd_putc('A');
        lcd_itoa( payload[0] );

        lcd_puts("\n");

        lcd_putc('B');
        lcd_itoa( payload[1] );
        lcd_putc(' ');

        lcd_putc('C');
        lcd_itoa( payload[2] );

        lcd_puts("\n");

        lcd_putc('D');
        lcd_itoa( payload[3] );
        lcd_putc(' ');

        lcd_putc('E');
        lcd_itoa( payload[4] );

        lcd_puts("\n");
        uint16_t out;
        out = payload[0];
        lcd_putc('s');
        itoa(out, itoabuffer, 10);
        lcd_puts(itoabuffer);
        lcd_putc(' ');

        out = payload[1] | (payload[2]<<8);
        lcd_putc('t');
        itoa(out, itoabuffer, 10);
        lcd_puts(itoabuffer);
        lcd_putc(' ');

        out = payload[3] | (payload[4]<<8);
        lcd_putc('h');
        itoa(out, itoabuffer, 10);
        lcd_puts(itoabuffer);
        lcd_putc(' ');
    }
}

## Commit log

2013-06-21 started project
    [sensor.brd, sensor.sch]
2013-06-25 first draft of master circuit
    [master.brd, master.sch]
2013-06-26 fileencoding, strict prototype warnings
2013-06-27 moved dht22 and uart to external libs
2013-06-27 use externalized uart/dht22 libs
2013-06-27 start uc specific code – attiny2313
2013-06-27 added watch crystal to master, notes for sensor
    [master.brd, master.sch, sensor.brd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]
2013-06-27 switch to 2313a for nicer header io definitions
2013-06-29 no SS in spi-lib, code formating
2013-06-29 added spi for usi on attiny2313(a)
2013-06-29 move pin definitions from lib to project
2013-06-29 di == miso, do == mosi for usi in spi mode
    [sensor.brd, sensor.sch]
2013-07-01 series resistors for shared spi/isp interface
    [master.brd, master.sch, sensor.brd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]
2013-07-04 switch sensor to attiny2313a
    [sensor-tiny2313a.brd, sensor-tiny2313a.sch, sensor.brd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]
2013-07-06 deluxe sensor board with lcd and everything
    [sensor-mega169a.brd, sensor-mega169a.sch]
2013-07-07 removed really complicating lcd from small version, layouted single sided pcb
    [sensor-tiny2313a.brd, sensor-tiny2313a.sch]
2013-07-07 outdated pin config, no double usage now -> can be removed
2013-07-07 changed irlml* parts to own library with better footprint
    [sensor-mega169a.brd, sensor-mega169a.sch, sensor-tiny2313a.brd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]
2013-07-08 atmega1284 is pin compatible
    [master.brd, master.sch]
2013-07-08 removed useless layers
    [sensor-mega169a.sch]
2013-07-08 create proper header file with prototypes
2013-07-08 cc-by-sa license
    [sensor-mega169a.brd, sensor-mega169a.sch, sensor-tiny2313a.brd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]
2013-07-08 added jumper for spi slave extensions on isp header
    [sensor-mega169a.brd, sensor-mega169a.sch]
2013-07-08 power up function
2013-07-09 rearranged some wires
    [sensor-mega169a.brd]
2013-07-09 hanged to xmega, better performance at lower price
    [sensor-xmegab3.brd, sensor-xmegab3.sch]
2013-07-10 some rerouting
    [sensor-xmegab3.brd, sensor-xmegab3.sch]
2013-07-12 added forgotten lan interface
    [master.brd, master.sch]
2013-07-13 improved spacing between some layers
    [master.brd, master.sch]
2013-07-13 sensor-xmega3 top+bottom silk screen arranged
    [sensor-xmegab3.brd]
2013-07-13 updated usb socket device
    [sensor-xmegab3.brd, sensor-xmegab3.sch]
2013-07-13 quadrature decoder needs two successive pins for input -> swapped s1
    [master.brd, master.sch]
2013-07-14 changed dru to mm, measured lan socket
    [master.brd]
2013-07-14 changed dru, width and drills to oshpark (finer pitch)
    [master.brd, master.sch]
2013-07-14 added license+version information
    [master.brd, master.sch]
2013-07-14 +5V also in netclass power with bigger width
    [master.brd, master.sch]
2013-07-14 improved routing
    [master.brd, master.sch]
2013-07-14 moved x3 to the right
    [master.brd]
2013-07-15 added sd card interface
    [master.brd, master.sch]
2013-07-15 oshw logo, drc errors fixed
    [master.brd, master.sch]
2013-07-16 auto creation of images
    [master.brd, master.sch]
2013-07-16 further pcb/schem images
2013-07-16 moved some parts to test image diff
    [master.sch]
2013-07-16 moved silk prints off from pads
    [master.brd]
2013-07-16 moved SG1, more clearance around pdi
    [master.brd]
2013-07-16 0603 and sot23 got silk screen
    [master.brd, master.sch]
2013-07-17 decoupling cap for rtc
    [master.brd, master.sch]
2013-07-17 lcd connector changed to standard 2.54 pin header
    [master.brd, master.sch]
2013-07-18 attiny so20 package
    [sensor-tiny2313a.brd, sensor-tiny2313a.sch]
2013-07-18 deleted second sch sheet with case scribbling
    [sensor-tiny2313a.sch]
2013-07-18 renamed ic1->u1, u1->u2
    [sensor-tiny2313a.brd, sensor-tiny2313a.sch]
2013-07-18 CC-BY-SA for schematics and boards
2013-07-20 dht22 sometimes hang, add mosfet as low side reset switch
    [master.brd, master.sch]
2013-11-06 gnd plane reshaped
    [sensor-tiny2313a.brd, sensor-tiny2313a.sch]
2014-02-24 pulldown for boostup enable line
    [sensor-tiny2313a.brd, sensor-tiny2313a.sch, sensor-xmegab3.brd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]
2014-08-04 problems with first prototype
2014-08-04 free seg14/15, can't be used with lcd in use
    [sensor-xmegab3.brd, sensor-xmegab3.sch]
2014-08-04 reassign display pins
    fixes #1
    [sensor-xmegab3.brd, sensor-xmegab3.sch]

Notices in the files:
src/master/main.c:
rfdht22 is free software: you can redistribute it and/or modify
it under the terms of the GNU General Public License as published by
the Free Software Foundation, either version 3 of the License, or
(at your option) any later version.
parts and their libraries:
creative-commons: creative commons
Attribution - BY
